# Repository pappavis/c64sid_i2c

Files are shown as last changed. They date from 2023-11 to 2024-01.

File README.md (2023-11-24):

# c64sid_i2c
Commodore64 SID-chip <a href="https://ccrma.stanford.edu/~chet/projects/tech_content/6581.pdf" label="SID datasheet">6851</a> chiptunes player  WORK-in-PROGRESS

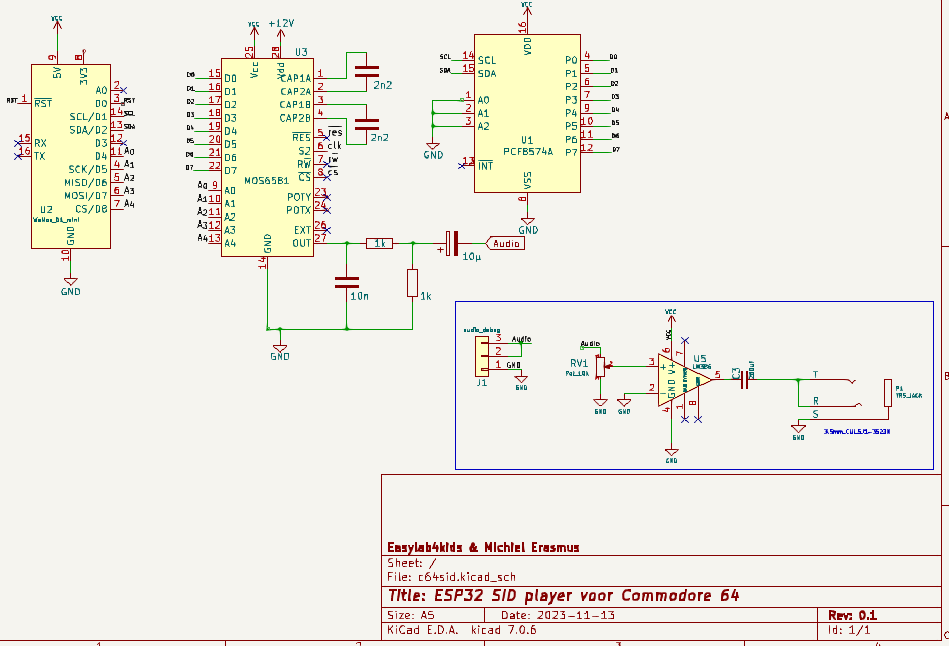
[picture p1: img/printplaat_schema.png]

<br><br>
Werk in uitvoering versie.<br>
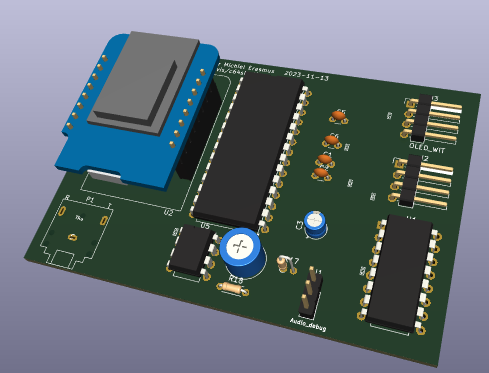
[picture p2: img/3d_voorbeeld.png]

<br>
door: Michiel Erasmus

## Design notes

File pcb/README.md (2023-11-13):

Dit is KiCAD bestand vir die printplaat.

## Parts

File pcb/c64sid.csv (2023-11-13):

Id | Designator | Footprint | Hoeveelheid | Orientatie | Leverancier en ref
1 | U3 | DIP-28_W15.24mm | 1 | MOS6581
2 | C6 | C_Disc_D3.0mm_W1.6mm_P2.50mm | 1 | 10n
3 | J1 | PinHeader_1x03_P2.54mm_Vertical | 1 | audio_debug
4 | R17 | R_Axial_DIN0204_L3.6mm_D1.6mm_P1.90mm_Vertical | 1 | 1k
5 | R18 | R_Axial_DIN0204_L3.6mm_D1.6mm_P5.08mm_Horizontal | 1 | 1k
6 | C1,C2 | C_Disc_D3.0mm_W1.6mm_P2.50mm | 2 | 2n2
7 | U5 | DIP-8_W7.62mm | 1 | LM386
8 | J3 | PinHeader_1x04_P2.54mm_Horizontal | 1 | OLED_wit
9 | U1 | DIP-16_W10.16mm | 1 | PCF8574A
10 | P1 | Jack_3.5mm_CUI_SJ1-3523N_Horizontal | 1 | TRS_JACK
11 | C3 | CP_Radial_D4.0mm_P2.00mm | 1 | 250uF
12 | RV1 | Potentiometer_Bourns_3339P_Vertical | 1 | Pot_10k
13 | J2 | PinHeader_1x04_P2.54mm_Horizontal | 1 | debug
14 | U2 | WEMOS_D1_mini_light | 1 | WeMos_D1_mini
15 | C5 | C_Disc_D3.0mm_W1.6mm_P2.50mm | 1 | 10µ

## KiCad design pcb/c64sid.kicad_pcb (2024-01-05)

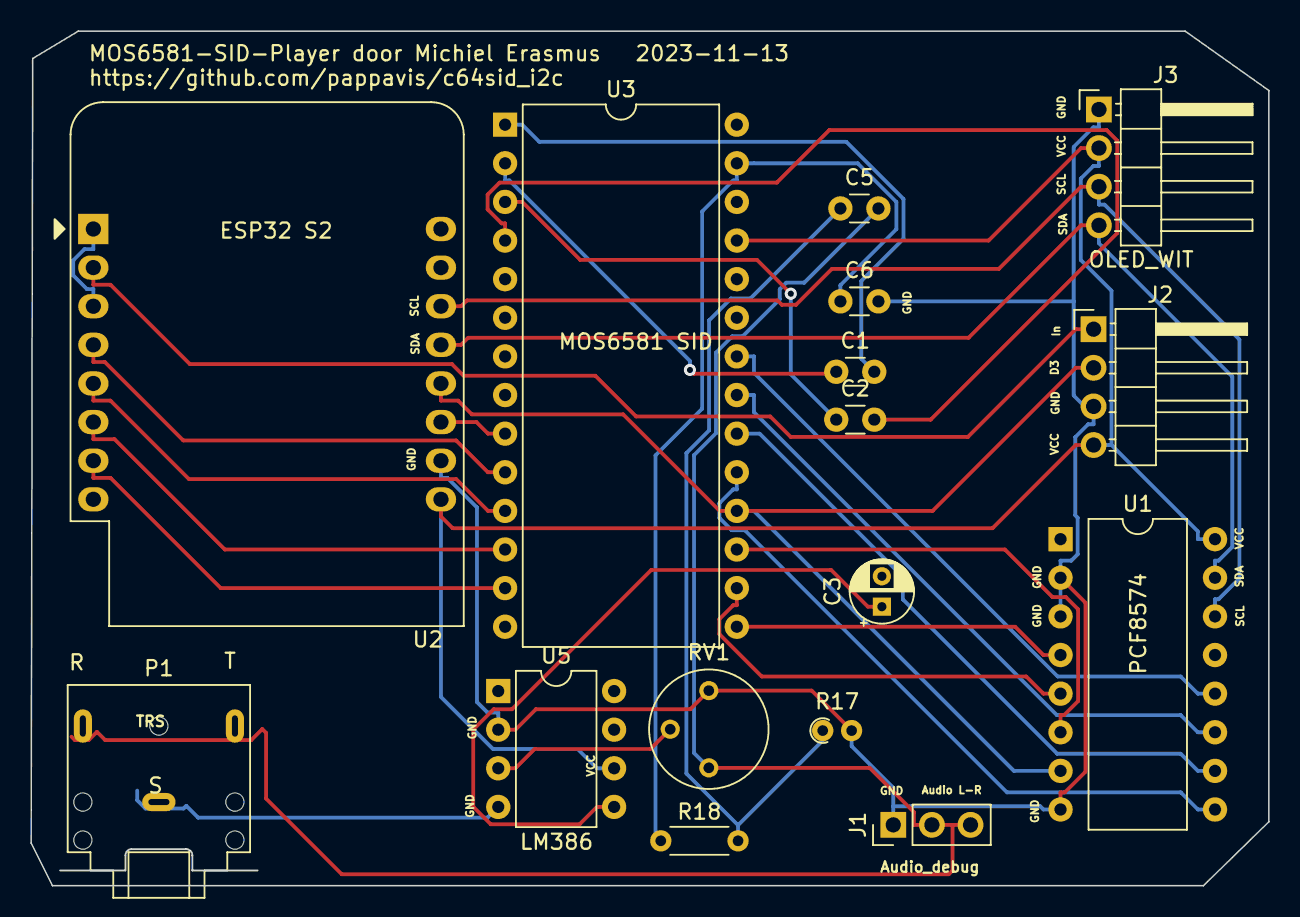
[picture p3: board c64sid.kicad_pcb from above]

Board: 2 copper layers, 81.4 x 56.2 mm, 16 parts (0 on the bottom side), 28 nets.

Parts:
C1, C2: 2n2; C_Disc_D3.0mm_W1.6mm_P2.50mm
C3: 250uF; CP_Radial_D4.0mm_P2.00mm
C5: 10µ; C_Disc_D3.0mm_W1.6mm_P2.50mm
C6: 10n; C_Disc_D3.0mm_W1.6mm_P2.50mm
J1: audio_debug; PinHeader_1x03_P2.54mm_Vertical
J2: debug; PinHeader_1x04_P2.54mm_Horizontal
J3: OLED_wit; PinHeader_1x04_P2.54mm_Horizontal
P1: TRS_JACK; Jack_3.5mm_CUI_SJ1-3523N_Horizontal
R17: 1k; R_Axial_DIN0204_L3.6mm_D1.6mm_P1.90mm_Vertical
R18: 1k; R_Axial_DIN0204_L3.6mm_D1.6mm_P5.08mm_Horizontal
RV1: Pot_10k; Potentiometer_Bourns_3339P_Vertical
U1: PCF8574A; DIP-16_W10.16mm
U2: WeMos_D1_mini; WEMOS_D1_mini_light
U3: MOS6581; DIP-28_W15.24mm
U5: LM386; DIP-8_W7.62mm

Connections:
/A_{0}: U2.11 (D4), U3.9 (A0)
/A_{1}: U2.4 (SCK/D5), U3.10 (A1)
/A_{2}: U2.5 (MISO/D6), U3.11 (A2)
/A_{3}: U2.6 (MOSI/D7), U3.12 (A3)
/A_{4}: U2.7 (CS/D8), U3.13 (A4)
/D0: U1.4 (P0), U3.15 (D0)
/D1: U1.5 (P1), U3.16 (D1)
/D2: U1.6 (P2), U3.17 (D2)
/D3: J2.2, U1.7 (P3), U2.12 (D3), U3.18 (D3)
/D4: U1.9 (P4), U3.19 (D4)
/D5: U1.10 (P5), U3.20 (D5)
/D6: U1.11 (P6), U3.21 (D6)
/D7: U1.12 (P7), U3.22 (D7)
/In: J2.1, U2.2 (A0)
/RST: U2.1 (~RST), U2.3 (D0)
/SCL: J3.3, U1.14 (SCL), U2.14 (SCL/D1)
/SDA: J3.4, U1.15 (SDA), U2.13 (SDA/D2)
Audio: C5.2, J1.2, J1.3, RV1.1
GND: C6.2, J1.1, J2.3, J3.1, R17.2, RV1.3, U1.2 (A1), U1.3 (A2), U1.8 (VSS), U2.10 (GND), U5.2 (-), U5.4 (GND)
unnamed: C3.1, U5.5
unnamed: C5.1, R17.1, R18.2
unnamed: C1.2, U3.1 (CAP1A)
unnamed: C2.1, U3.3 (CAP1B)
unnamed: C1.1, U3.2 (CAP2A)
unnamed: C2.2, U3.4 (CAP2B)
unnamed: C6.1, R18.1, U3.27 (OUT)
unnamed: RV1.2, U5.3 (+)
VCC: J2.4, J3.2, U1.16 (VDD), U2.9 (5V), U3.25 (Vcc), U5.6 (V+)

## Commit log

2023-11-13 Proef commit
    [c64sid.kicad_sch]
2024-01-05 PCB gerbers naar jlcpcb.com
    [c64sid-B_Cu.gbr, c64sid-B_Mask.gbr, c64sid-B_Paste.gbr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]
